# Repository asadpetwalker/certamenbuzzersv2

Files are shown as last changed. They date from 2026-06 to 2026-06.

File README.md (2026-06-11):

# CertamenBuzzersV2

A buzzer system for the game Certamen about Roman language, mythology, history, and culture. It is a quiz bowl style game, where whoever buzzes first gets a chance to claim the points.

# Why I made this

I made this because right now buzzer systems are inaccessible. Buzzer systems are sold by JCL, but they have a monopoly over it, so they mark up the prices incredibly even though the electronics are fairly simple, to 800 dollars. for the small version. I made this for my team, because they need a buzzer system to get practice in, since hyperbuzzing is an important strategy in more competitive leagues, as well as the fact that the current version is very bulky and you cannot bring it to places for practice.

# Wiring Diagram

Wire - Button - Wire

# Pictures

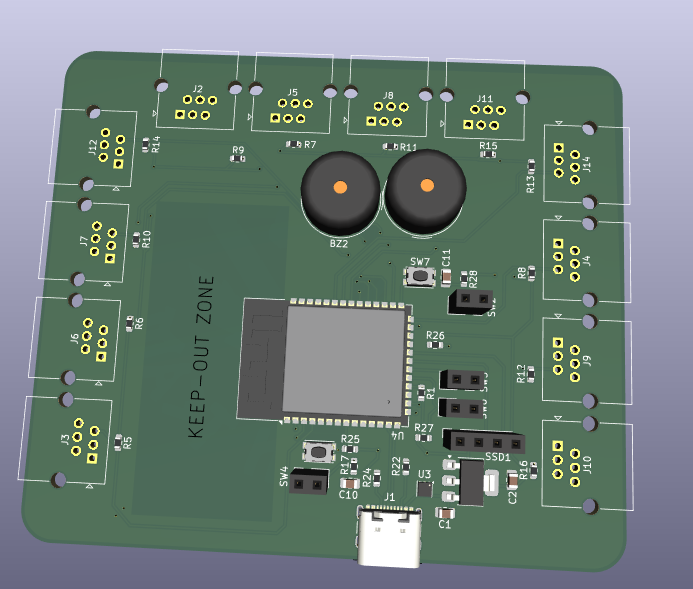
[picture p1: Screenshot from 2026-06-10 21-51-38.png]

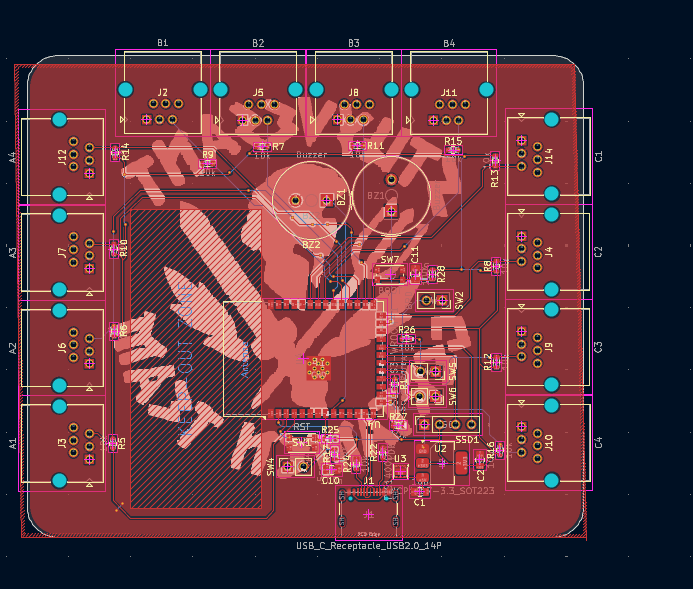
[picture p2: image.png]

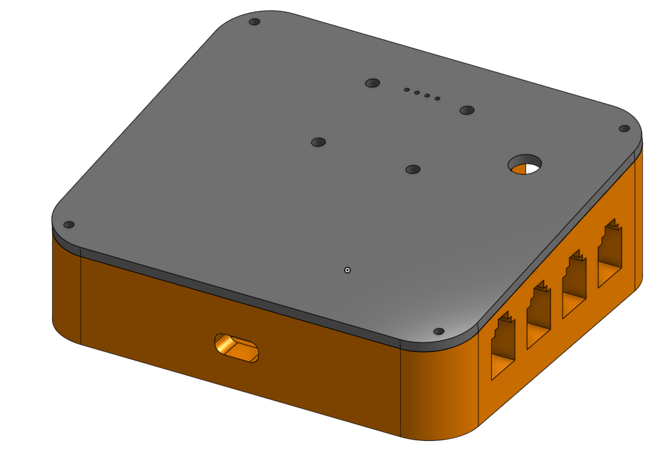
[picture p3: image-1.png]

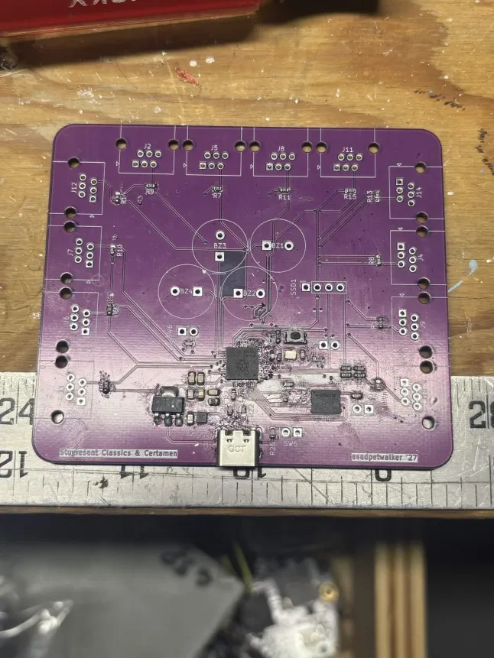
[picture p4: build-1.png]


# BOM

| Name | Purpose | Quantity | Total Cost (USD) | Link | Distributor |
|---|---|---|---|---|---|
| Soldering Iron | Soldering | 1 | 34.96 | [Amazon](https://www.amazon.com/Soldering-Temperature-200-480%E2%84%83-Compatible-Function/dp/B0FJDRF6S5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) | Amazon |
| 6P4C RJ11 Connector | Connecting to wires | 1 | 5.89 | [Amazon](https://www.amazon.com/Telephone-Modular-Connector-Compatible-Stranded/dp/B07YZ79DCY/ref=sr_1_3?sr=8-3) | Amazon |
| Buttons | Buttoning | 1 | 7.99 | [Amazon](https://www.amazon.com/Twidec-Momentary-Button-Pre-soldered-R13-507BK-X/dp/B0CYSSFWSS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) | Amazon |
| PCB + Stencil | PCB | 1 | 6.15 | | JLCPCB |
| 4 | RF TXRX MODULE BT PCB TRACE SMD | 2 | 10.42 | | Digikey |
| 3 | IC REG LINEAR 3.3V 1A SOT-223 | 2 | 0.76 | | Digikey |
| 2 | SWITCH TACTILE SPST-NO 0.05A 32V | 4 | 2.68 | | Digikey |
| 1 | RES 10K OHM 1% 1/10W 0603 | 50 | 0.75 | | Digikey |

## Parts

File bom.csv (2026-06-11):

Name | Purpose | Quantity | Total Cost (USD) | Link | Distributor
Soldering Iron | Soldering | 1 | 34.96 | https://www.amazon.com/Soldering-Temperature-200-480%E2%84%83-Compatible-Function/dp/B0FJDRF6S5 | Amazon
6P4C RJ11 Connector | Connecting to wires | 1 | 5.89 | https://www.amazon.com/Telephone-Modular-Connector-Compatible-Stranded/dp/B07YZ79DCY | Amazon
Buttons | Buttoning | 1 | 7.99 | https://www.amazon.com/Twidec-Momentary-Button-Pre-soldered-R13-507BK-X/dp/B0CYSSFWSS | Amazon
PCB + Stencil | PCB | 1 | 6.15 |  | JLCPCB
4 | RF TXRX MODULE BT PCB TRACE SMD | 2 | 10.42 |  | Digikey
3 | IC REG LINEAR 3.3V 1A SOT-223 | 2 | 0.76 |  | Digikey
2 | SWITCH TACTILE SPST-NO 0.05A 32V | 4 | 2.68 |  | Digikey
1 | RES 10K OHM 1% 1/10W 0603 | 50 | 0.75 |  | Digikey

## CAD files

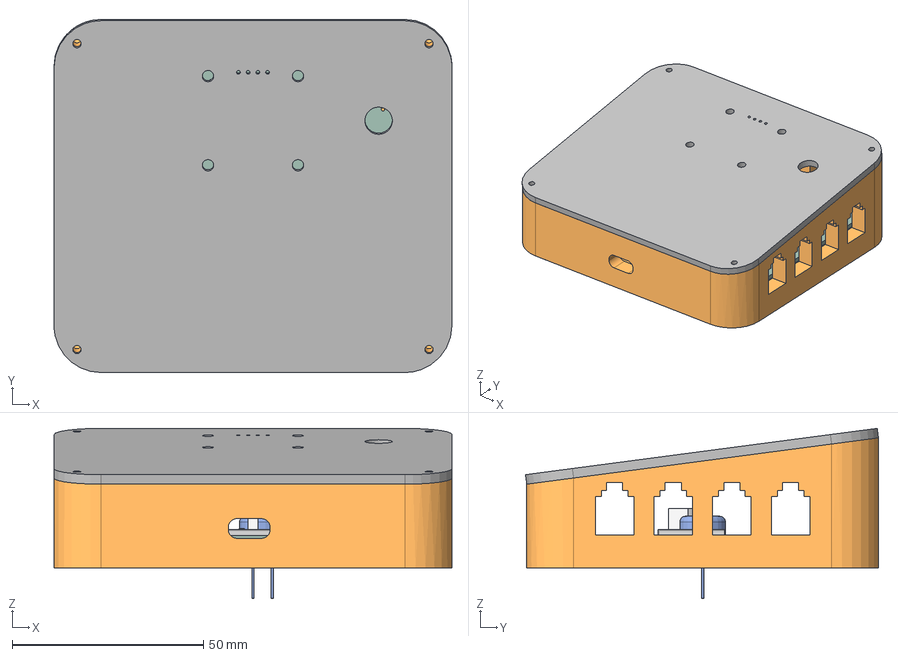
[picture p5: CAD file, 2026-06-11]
build.step
104.0 x 92.2 x 44.5 mm
ESP32-S3-WROOM-1 x 52
USB_C_Receptacle_GCT_USB4105-xx-A_16P_TopMnt_Horizontal x 36
PinSocket_1x04_P2.54mm_Vertical
SOT-223
PinSocket_1x02_P2.54mm_Vertical
SW_Push_1P1T_NO_CK_KMR2
CertamenBuzzersV2_PCB
Buzzer_TDK_PS1240P02BT_D12.2mm_H6.5mm
C_0805_2012Metric
R_0603_1608Metric
WSON-6-1EP_2x2mm_P0.65mm_EP1x1.6mm

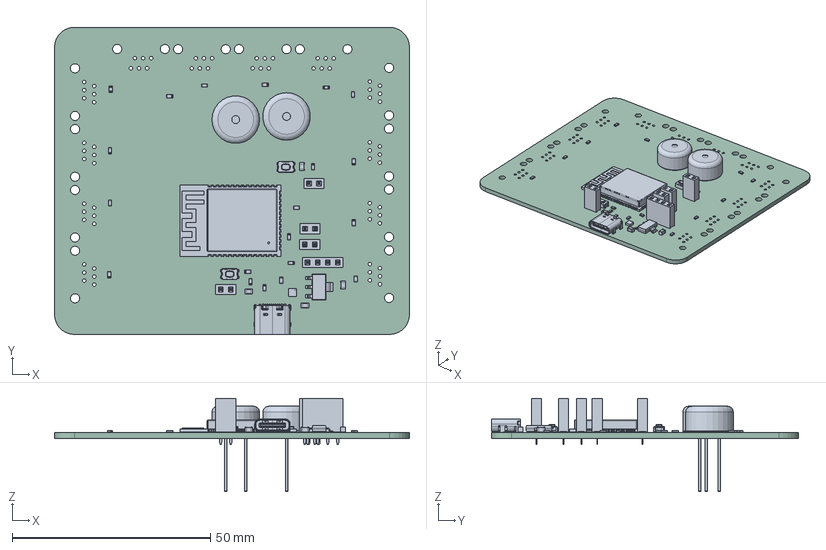
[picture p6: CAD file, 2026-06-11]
CertamenBuzzersV2/pcb.step
89.5 x 77.5 x 23.5 mm
C_0805_2012Metric x 4
R_0603_1608Metric x 20
ESP32-S3-WROOM-1
Buzzer_TDK_PS1240P02BT_D12.2mm_H6.5mm x 2
SW_Push_1P1T_NO_CK_KMR2 x 2
USB_C_Receptacle_GCT_USB4105-xx-A_16P_TopMnt_Horizontal
PinSocket_1x04_P2.54mm_Vertical
PinSocket_1x02_P2.54mm_Vertical x 4
WSON-6-1EP_2x2mm_P0.65mm_EP1x1.6mm
SOT-223
CertamenBuzzersV2_PCB

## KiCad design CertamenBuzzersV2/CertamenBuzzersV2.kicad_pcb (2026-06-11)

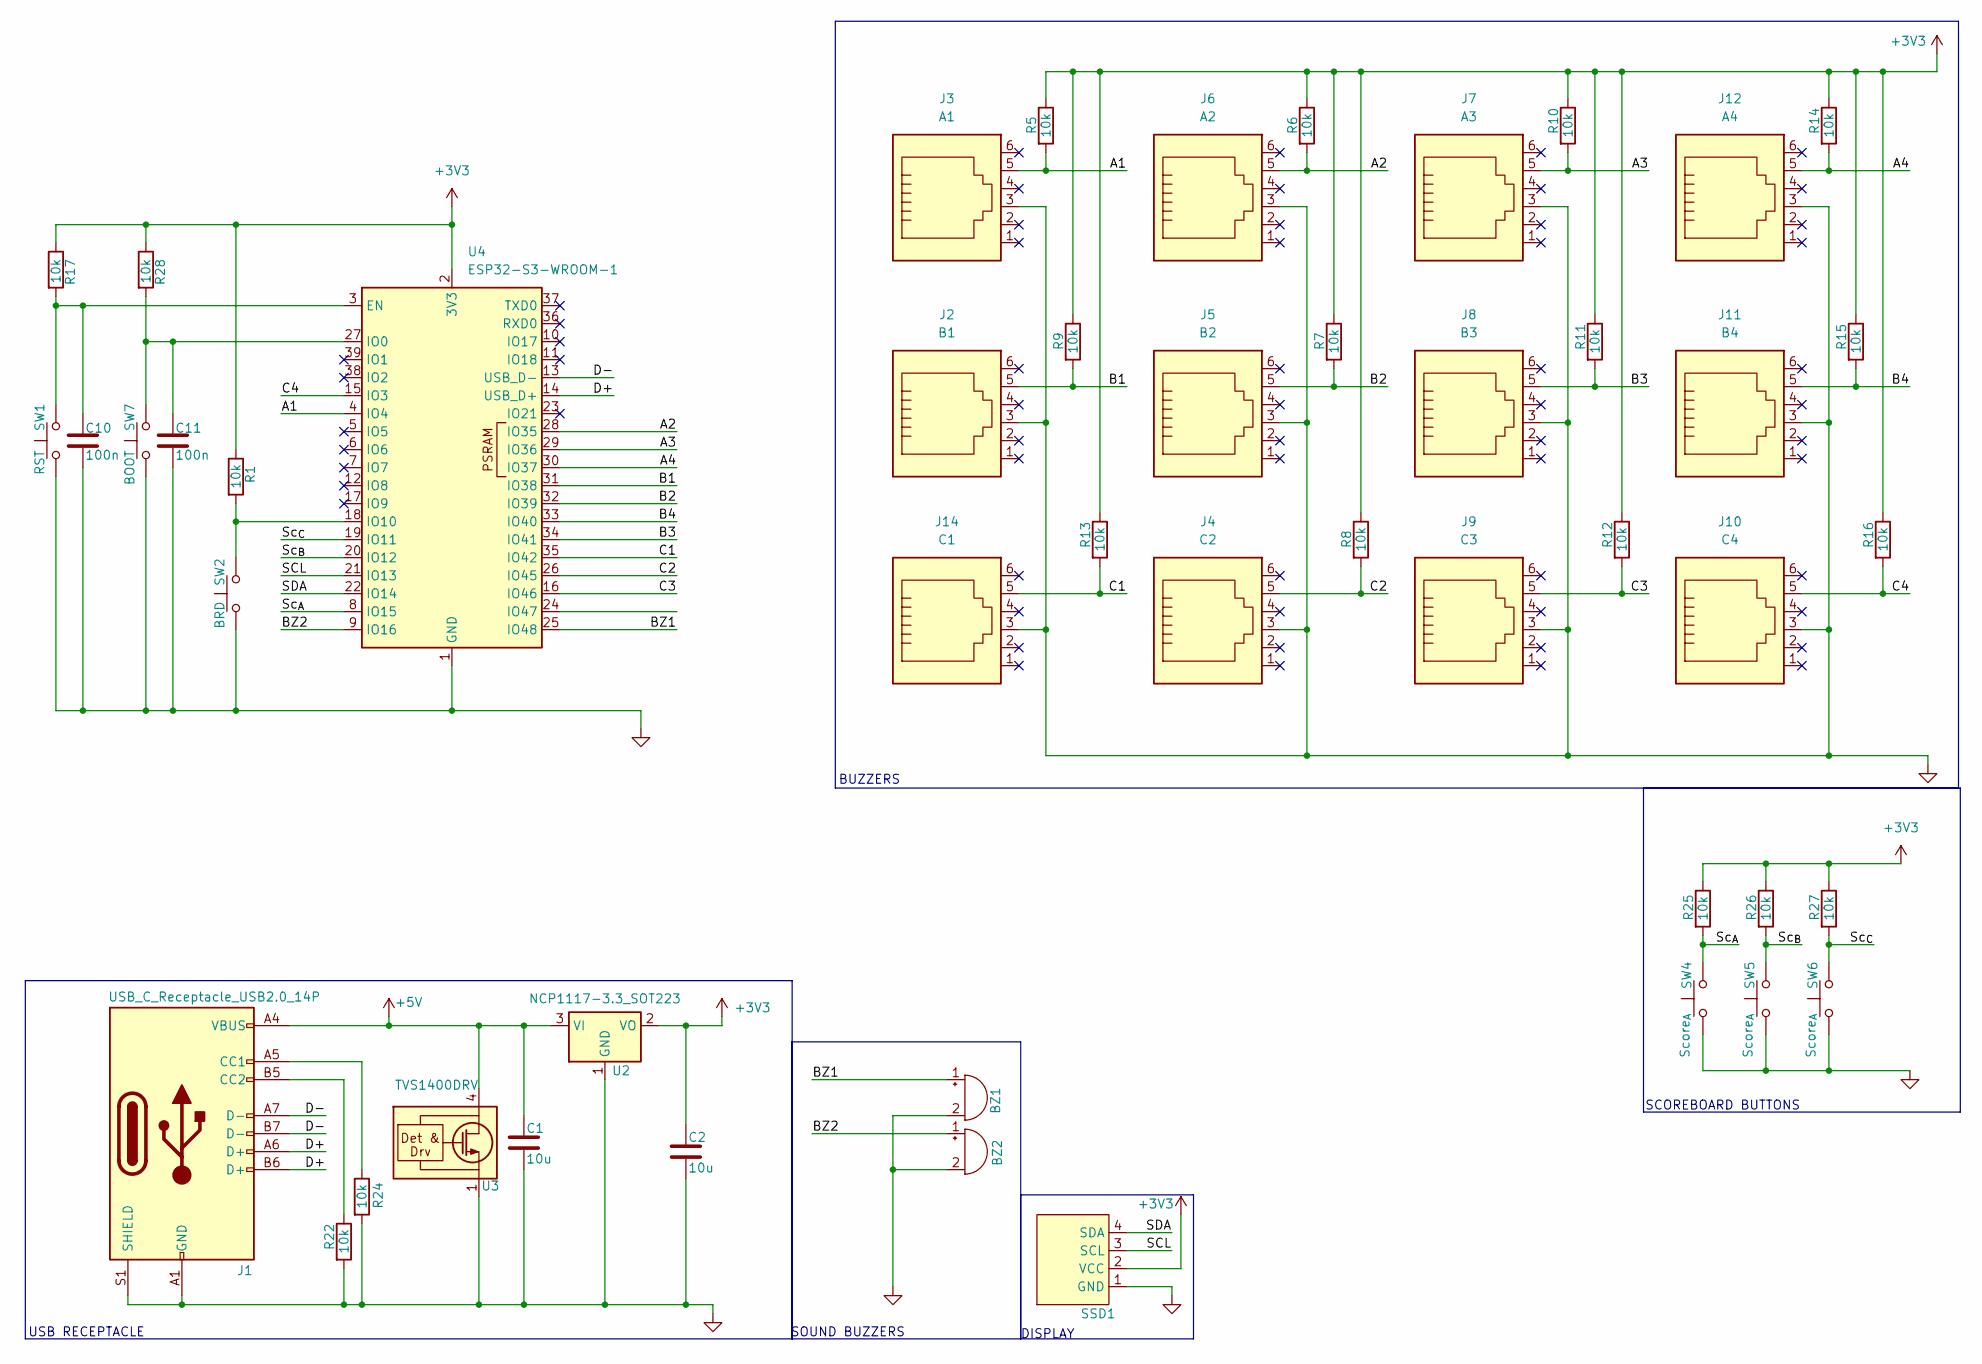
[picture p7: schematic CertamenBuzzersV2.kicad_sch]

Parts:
BZ1, BZ2: Buzzer; Buzzer_TDK_PS1240P02BT_D12.2mm_H6.5mm
C1, C2: 10u; C_0805_2012Metric
C10, C11: 100n; C_0805_2012Metric
J1: USB_C_Receptacle_USB2.0_14P; USB_C_Receptacle_GCT_USB4105-xx-A_16P_TopMnt_Horizontal
J2: B1; RJ25_Wayconn_MJEA-660X1_Horizontal
J3: A1; RJ25_Wayconn_MJEA-660X1_Horizontal
J4: C2; RJ25_Wayconn_MJEA-660X1_Horizontal
J5: B2; RJ25_Wayconn_MJEA-660X1_Horizontal
J6: A2; RJ25_Wayconn_MJEA-660X1_Horizontal
J7: A3; RJ25_Wayconn_MJEA-660X1_Horizontal
J8: B3; RJ25_Wayconn_MJEA-660X1_Horizontal
J9: C3; RJ25_Wayconn_MJEA-660X1_Horizontal
J10: C4; RJ25_Wayconn_MJEA-660X1_Horizontal
J11: B4; RJ25_Wayconn_MJEA-660X1_Horizontal
J12: A4; RJ25_Wayconn_MJEA-660X1_Horizontal
J14: C1; RJ25_Wayconn_MJEA-660X1_Horizontal
R1, R5, R6, R7, R8, R9, R10, R11, R12, R13, R14, R15, R16, R17, R22, R24, R25, R26, R27, R28: 10k; R_0603_1608Metric
SSD1: PinSocket_1x04_P2.54mm_Vertical
SW1: RST; SW_Push_1P1T_NO_CK_KMR2
SW2: BRD; PinSocket_1x02_P2.54mm_Vertical
SW4, SW5, SW6: Score_{A}; PinSocket_1x02_P2.54mm_Vertical
SW7: BOOT; SW_Push_1P1T_NO_CK_KMR2
U2: NCP1117-3.3_SOT223; SOT-223-3_TabPin2
U3: TVS1400DRV; WSON-6-1EP_2x2mm_P0.65mm_EP1x1.6mm
U4: ESP32-S3-WROOM-1

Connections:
+3V3: C2.1, R1.1, R5.1, R6.1, R7.1, R8.1, R9.1, R10.1, R11.1, R12.1, R13.1, R14.1, R15.1, R16.1, R17.1, R25.1, R26.1, R27.1, R28.1, SSD1.2 (VCC), U2.2 (VO), U4.2 (3V3)
+5V: C1.1, J1.A4 (VBUS), J1.A9 (VBUS), J1.B4 (VBUS), J1.B9 (VBUS), U2.3 (VI), U3.4 (IN), U3.5 (IN), U3.6 (IN)
/A1: J3.5, R5.2, U4.4 (IO4)
/A2: J6.5, R6.2, U4.28 (IO35)
/A3: J7.5, R10.2, U4.29 (IO36)
/A4: J12.5, R14.2, U4.30 (IO37)
/B1: J2.5, R9.2, U4.31 (IO38)
/B2: J5.5, R7.2, U4.32 (IO39)
/B3: J8.5, R11.2, U4.34 (IO41)
/B4: J11.5, R15.2, U4.33 (IO40)
/BZ1: BZ1.1 (+), U4.25 (IO48)
/BZ2: BZ2.1 (+), U4.9 (IO16)
/C1: J14.5, R13.2, U4.35 (IO42)
/C2: J4.5, R8.2, U4.26 (IO45)
/C3: J9.5, R12.2, U4.16 (IO46)
/C4: J10.5, R16.2, U4.15 (IO3)
/D+: J1.A6 (D+), J1.B6 (D+), U4.14 (USB_D+)
/D-: J1.A7 (D-), J1.B7 (D-), U4.13 (USB_D-)
/SCL: SSD1.3 (SCL), U4.21 (IO13)
/SDA: SSD1.4 (SDA), U4.22 (IO14)
/Sc_{A}: R25.2, SW4.2, U4.8 (IO15)
/Sc_{B}: R26.2, SW5.2, U4.20 (IO12)
/Sc_{C}: R27.2, SW6.2, U4.19 (IO11)
GND: BZ1.2 (-), BZ2.2 (-), C1.2, C2.2, C10.2, C11.2, J1.A1 (GND), J1.A12 (GND), J1.B1 (GND), J1.B12 (GND), J1.S1 (SHIELD), J2.3, J3.3, J4.3, J5.3, J6.3, J7.3, J8.3, J9.3, J10.3, J11.3, J12.3, J14.3, R22.2, R24.2, SSD1.1 (GND), SW1.1, SW2.1, SW4.1, SW5.1, SW6.1, SW7.1, U2.1 (GND), U3.1 (GND), U3.2 (GND), U3.3 (GND), U3.7 (GND), U4.1 (GND), U4.40 (GND), U4.41 (GND)
unnamed: J1.A5 (CC1), R24.1
unnamed: J1.B5 (CC2), R22.1
unnamed: C10.1, R17.2, SW1.2, U4.3 (EN)
unnamed: C11.1, R28.2, SW7.2, U4.27 (IO0)
unnamed: R1.2, SW2.2, U4.18 (IO10)

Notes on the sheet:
SOUND BUZZERS
DISPLAY
BUZZERS
USB RECEPTACLE
SCOREBOARD BUTTONS

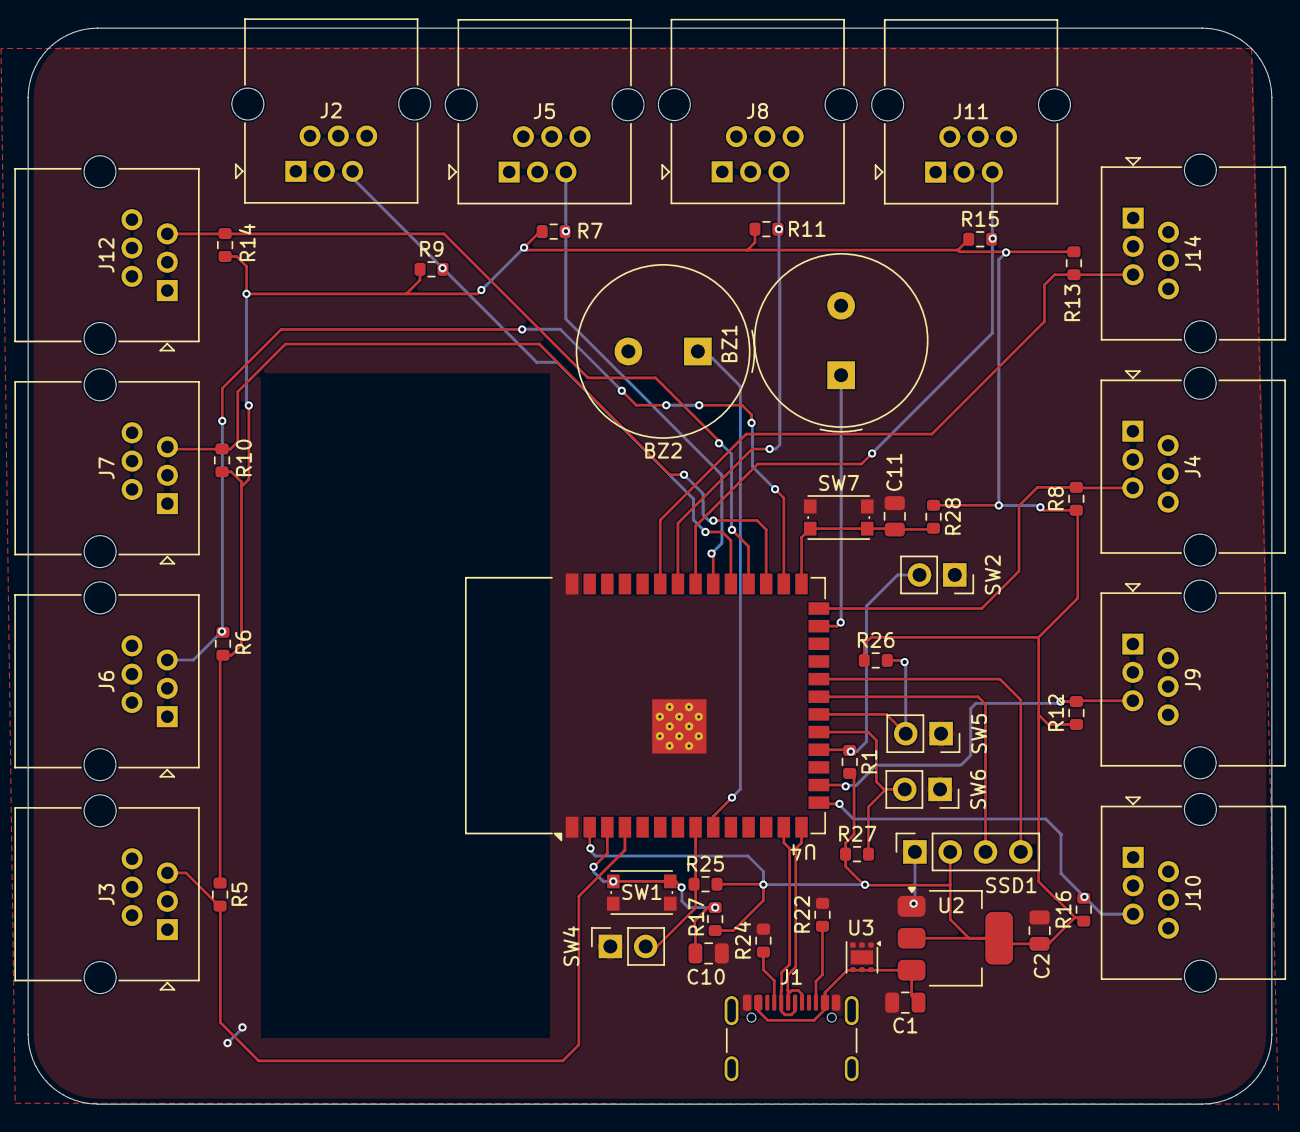
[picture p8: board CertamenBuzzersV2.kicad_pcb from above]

Board: 2 copper layers, 89.5 x 77.4 mm, 49 parts (0 on the bottom side), 29 nets.
